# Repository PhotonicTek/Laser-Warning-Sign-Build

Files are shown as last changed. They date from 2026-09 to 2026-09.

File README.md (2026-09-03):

# Laser Warning Sign
---
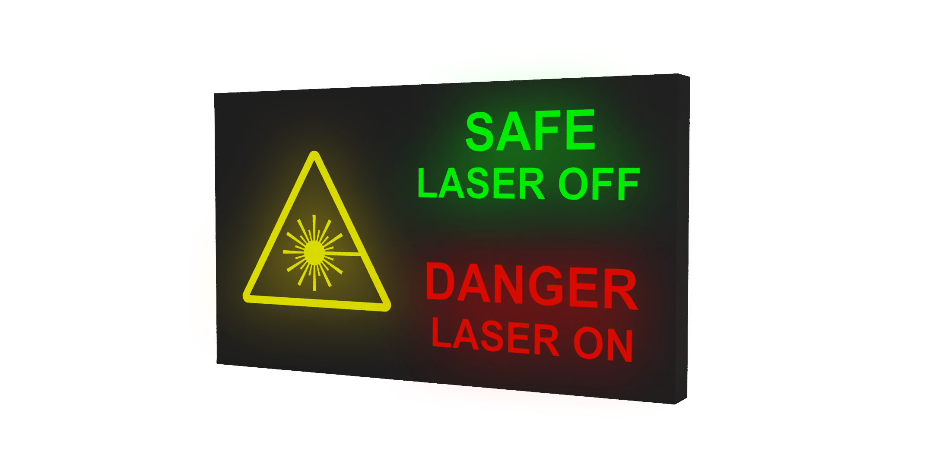
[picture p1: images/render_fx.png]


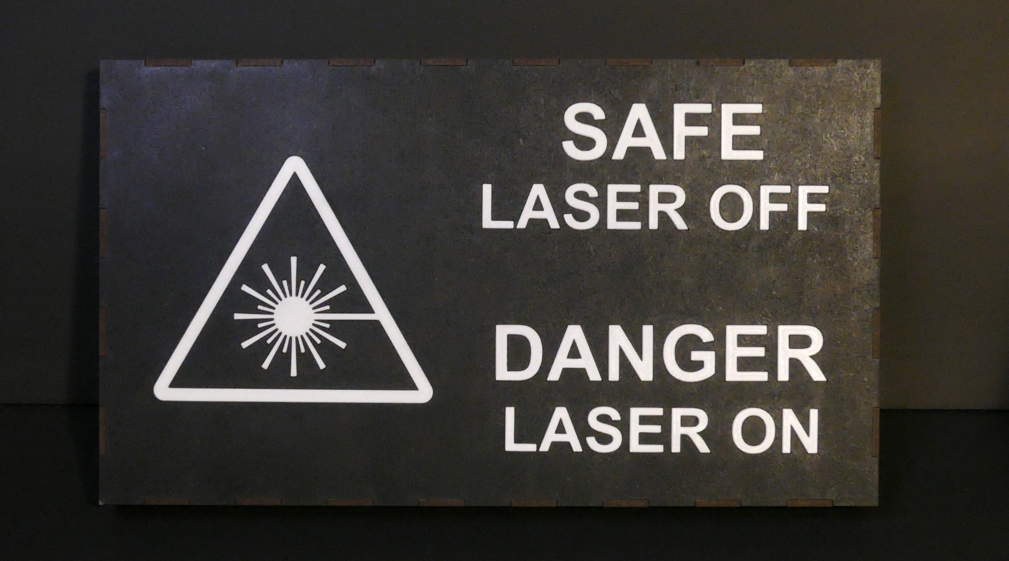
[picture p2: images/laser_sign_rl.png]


---

## Background

I wanted a warning sign that's better than just a paper sign taped to the door. This repo contains everything needed to reproduce the sign and its matching remote: schematics, code, 3D model files, laser cutter files, a parts list, and image assets.

Video walkthrough of the design and build process: *[[Building a Wireless Laser Warning Sign]](https://youtu.be/S0kvliff3TM)*

---

## Overview

The sign has two states, safe and danger, lit from behind by an LED strip through a diffuse layer, with laser-cut lettering and icon. It's fully battery-operated, wirelessly switched by a handheld remote, and mounts with command strips.

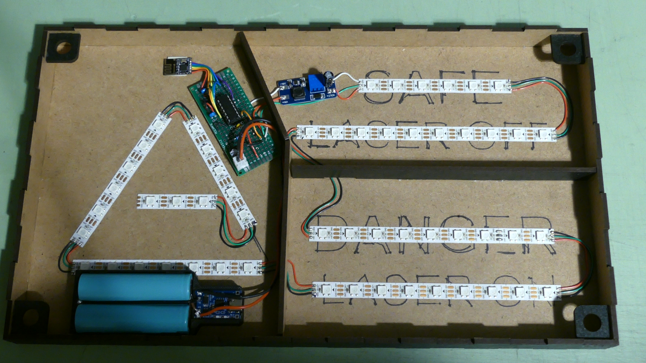
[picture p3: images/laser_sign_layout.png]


### Sign Electronics
- **ATtiny84** — main microcontroller, chosen for size, low-power sleep states, and flexible power input
- **nRF24** — wireless transceiver, receives state changes from the remote
- **AP7313** — low-dropout regulator, steps battery voltage down to keep the nRF24 under its 3.6V max
- **MT3608** — boost converter, steps battery voltage up to 5V for the LED strip
- **WS2812B (NeoPixel) LED strip** — backlighting for the lettering
- **TP4056** — battery management / charging
- **2x 18650 cells 3000mAh (parallel)** — ~6000mAh combined capacity; recycled cells were tested and verified to ~2780mAh
- **IRLML6402TRPBF** high-side MOSFET — cuts power to the boost converter and LEDs when the sign is off, to eliminate idle draw from that stage

### Remote Electronics
Same microcontroller and transceiver as the sign, with button inputs instead of an LED strip. Powers on when the power button is pressed and transmits the selected sign state.

### Power Notes
- Idle draw when duty-cycled (~1s sleep, brief wake to check for a signal, ~2.5% duty cycle): averages ~640µA, giving roughly a year of standby life
- With the sign on (LEDs lit): ~560mA, ~10 hours of runtime

The ATtiny84 doesn't have onboard USB, so it's flashed using an Arduino Uno as an ISP programmer.

---

## Repository Contents

- Schematics are provided as source .json files plus image exports for viewing without a schematic program.
- 3D model files for the full sign and remote plus individual 3D-printed parts, all printing was done in PLA on a Bambu Lab P1S.
- LightBurn laser files are set up for 3mm hardboard. Additional DXF and SVG cut paths are also available.
- The BOM lists parts as used; substitutions are noted where relevant (see below).

---

## Substitution Notes

- Generic resistors, capacitors, and other passives can be substituted freely at the correct value/tolerance.
- The ATtiny84 and nRF24 modules are both common and easily sourced new. The nRF24 module comes in many shapes and sizes; the mini version was used in this project as it was what I had on hand.
- 18650 cells used here were recycled/harvested, capacity and health will very if you're sourcing your own.

---

## Known Issues / Things to Watch For

- The boost converter causes a brief voltage drop on power-up that can brown out the microcontroller and cause the LED strip to briefly show garbage colors. A large capacitor on the boost converter output and a small capacitor across the MOSFET gate (to slow its turn-on) fixes this. Both fixes have been implemented and are shown on the schematics in this repo.
- Make sure to burn the bootloader on the ATtiny84 before programming, skipping this leaves the clock running at the wrong speed.
- Light leakage around the lettering in the dark may need internal dividers depending on your enclosure tolerances.

---

## Licence

Everything in this repository — schematics, code, models, cut files, BOM, and images, is free to use, modify, and build on, for any purpose.

**No support is provided.** This is a documentation dump, not a maintained project. I won't be providing build help, debugging, or answering setup questions, use it at your own discretion.

---

## AI Use Disclaimer

Portions of this documentation were drafted with the use of AI writing tools and reviewed for accuracy against the physical build. All technical content (circuit design, firmware, and component selection) came from the actual build process. If you spot an error, please open an issue.

---

## See Also

- Video walkthrough: *[[Building a Wireless Laser Warning Sign]](https://youtu.be/S0kvliff3TM)*
- KiCad / EasyEDA (schematic tools): https://www.kicad.org / https://easyeda.com
- Krita (used for the initial sign mockup): https://krita.org

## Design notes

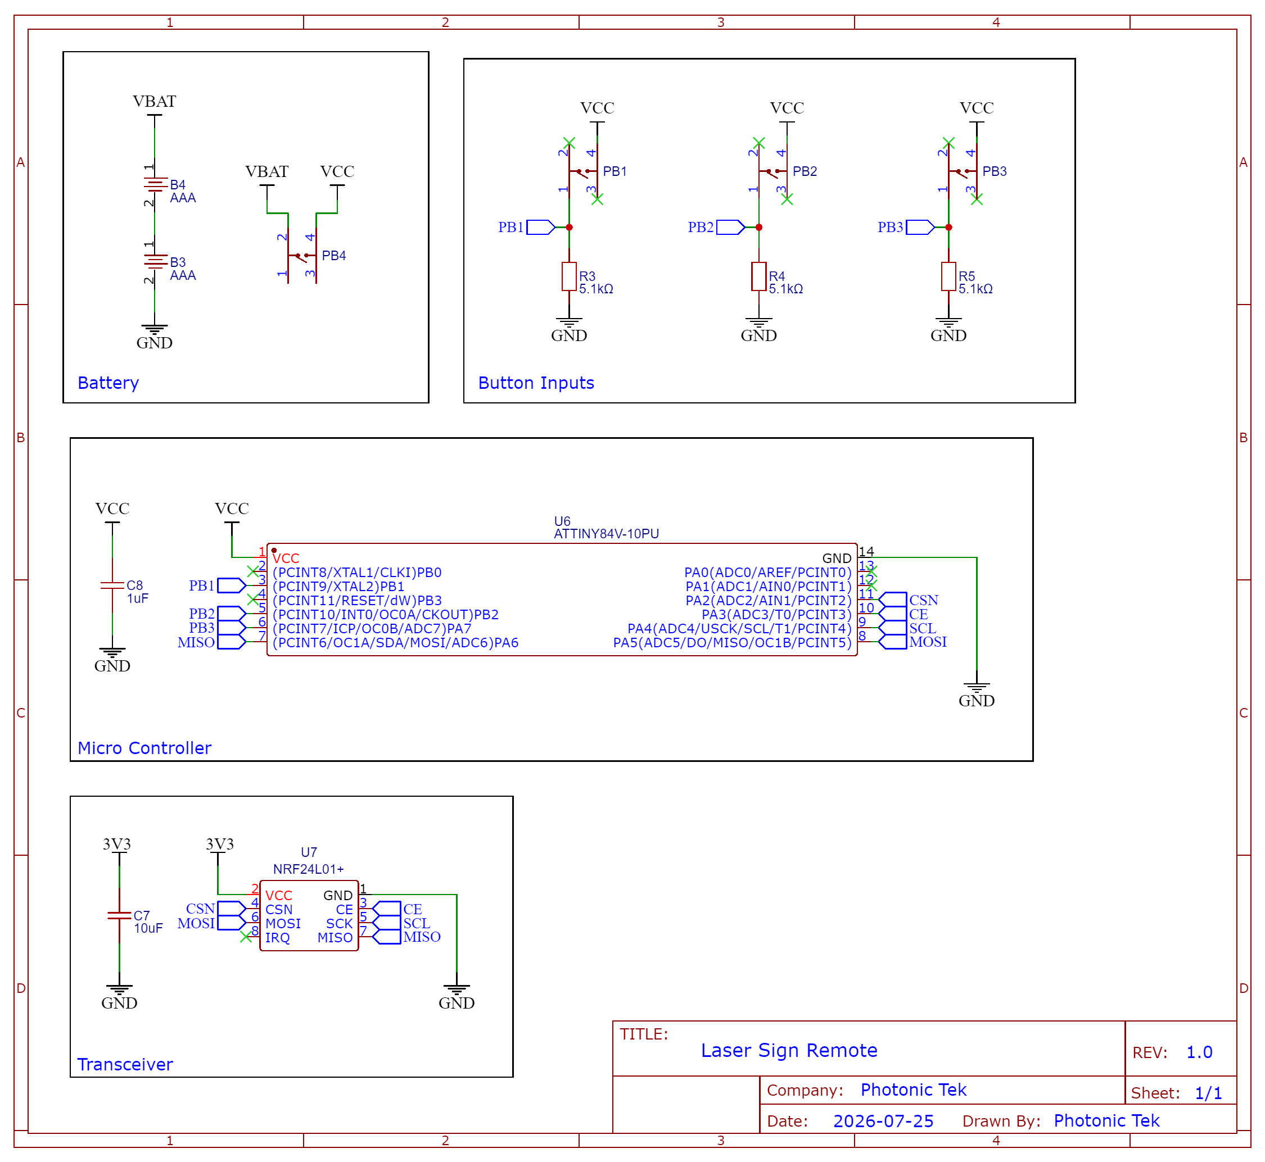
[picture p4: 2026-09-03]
schematics/Laser_Sign_Remote.png

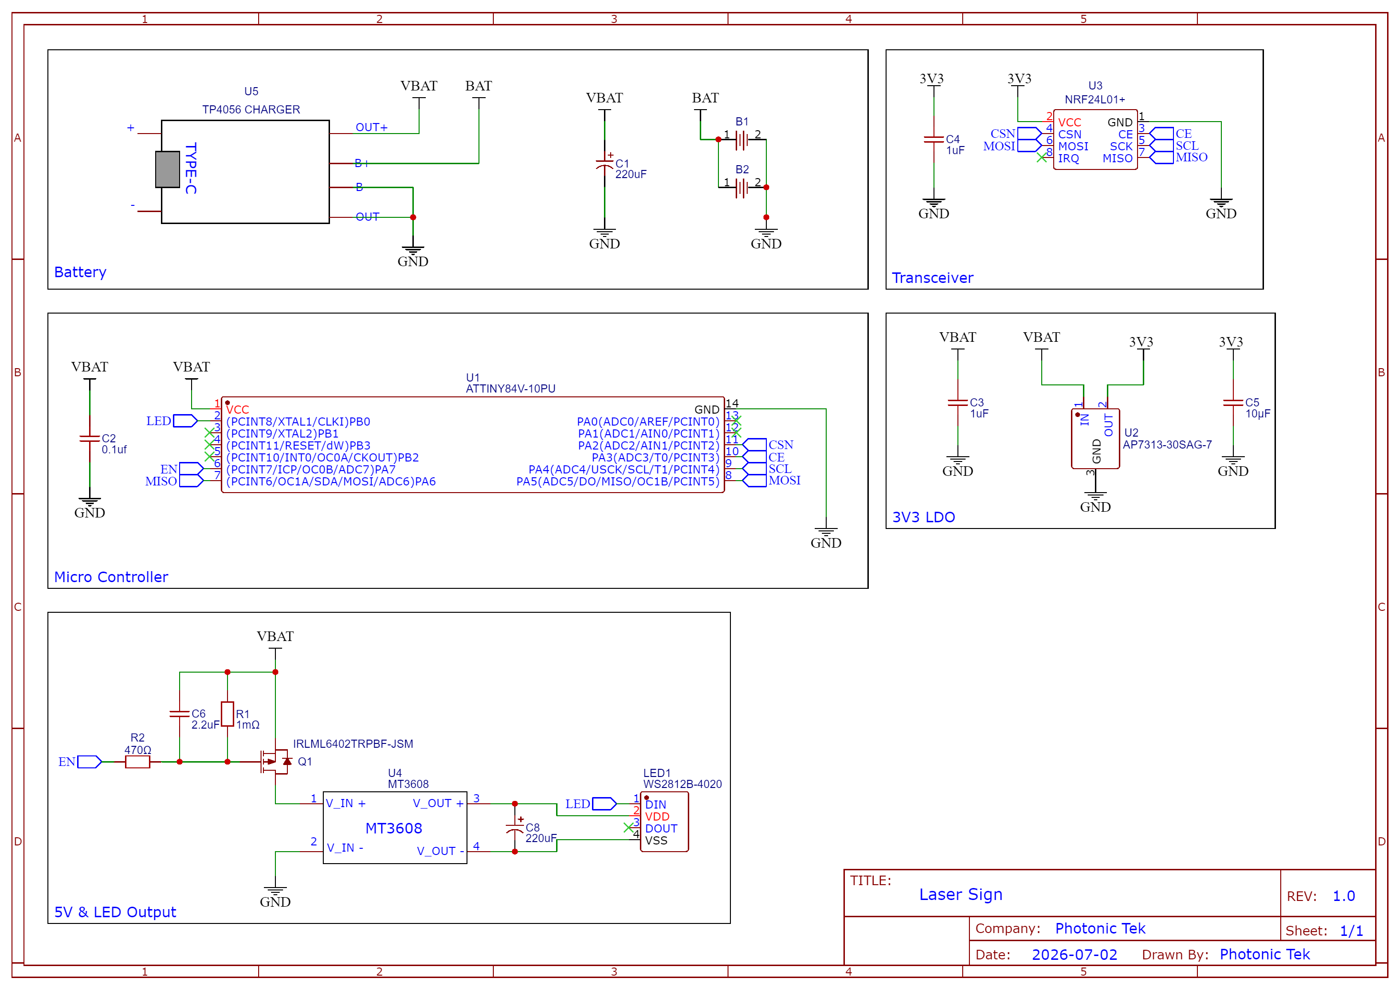
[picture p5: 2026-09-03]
schematics/Laser_Sign.png

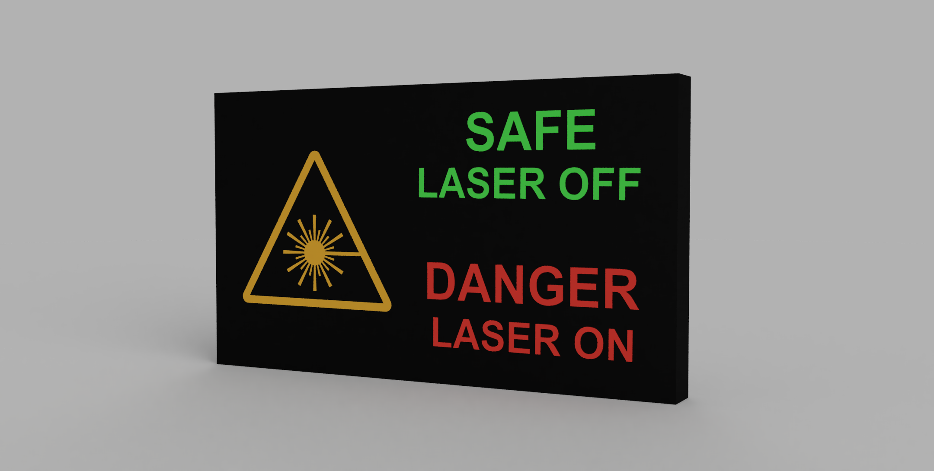
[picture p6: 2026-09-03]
images/render.png

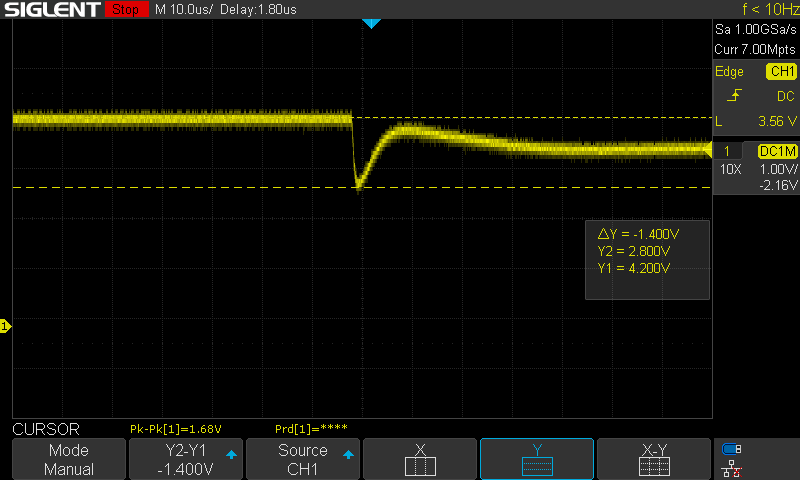
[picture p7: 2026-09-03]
images/Video_Asset2.png

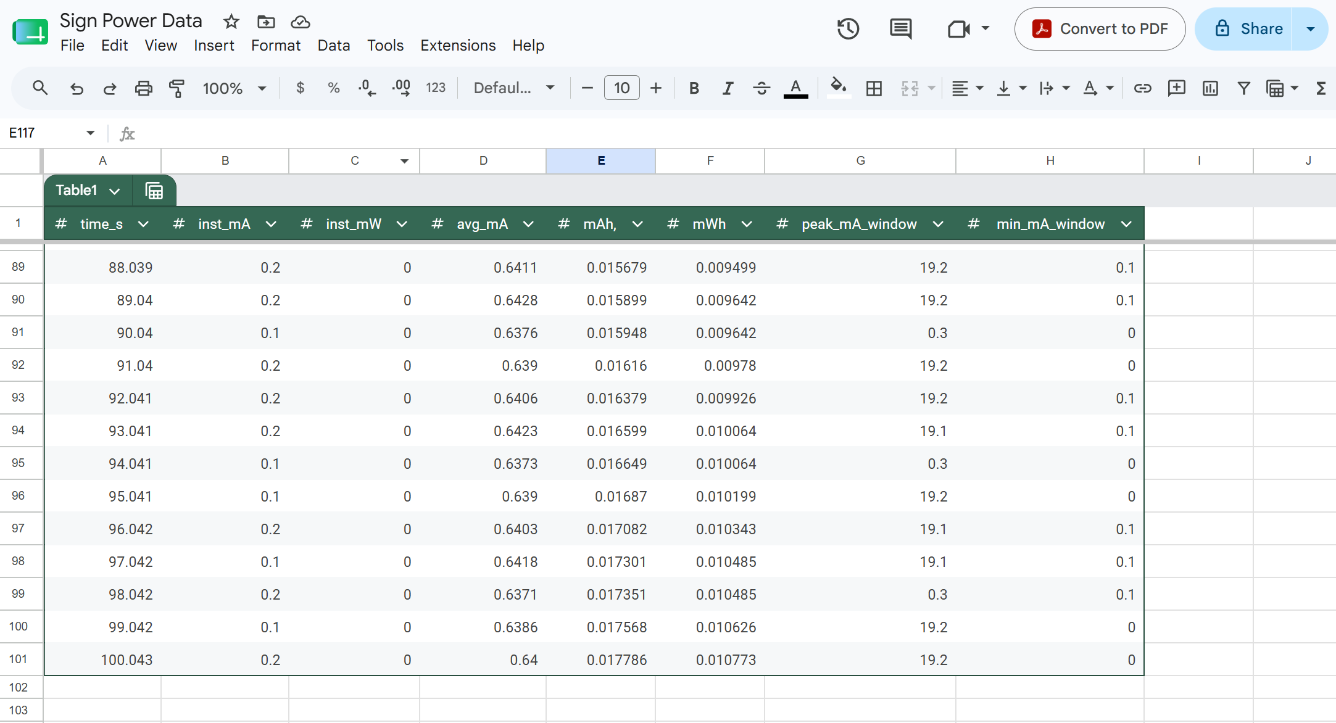
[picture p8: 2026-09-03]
images/Video_Asset5.png

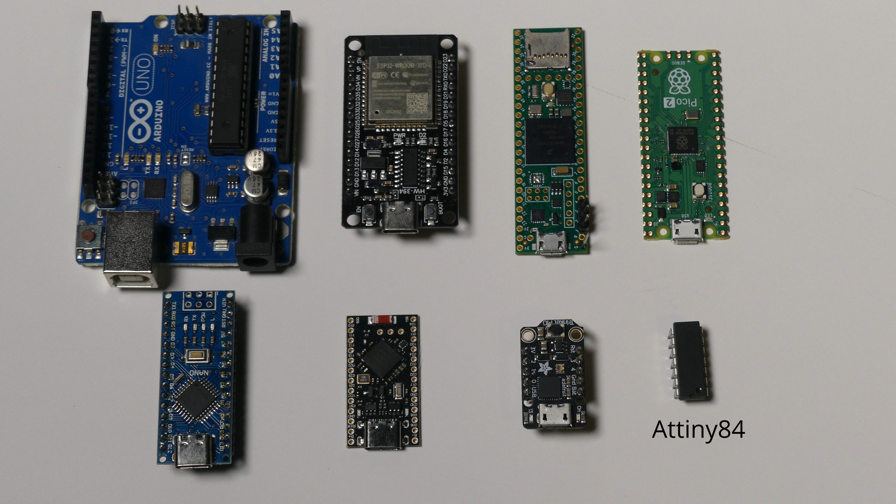
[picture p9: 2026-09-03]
images/Video_Asset1.jpg

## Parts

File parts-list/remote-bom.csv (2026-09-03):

ID | Designator | Quantity | Name | Notes / Link
1 | B3,B4 | 2 | AAA Battery
2 | C8 | 1 | 1uF
3 | C9 | 1 | 10uF
4 | R3,R4,R5 | 3 | 5.1kOhm
5 | PB1,PB2,PB3,PB4 | 4 | Tactile Button
6 | U6 | 1 | ATTINY84V-10PU | https://www.digikey.ca/en/products/detail/microchip-technology/ATTINY84V-10PU/1245918
7 | U7 | 1 | NRF24L01+ | https://www.aliexpress.com/item/1005009894884618.html

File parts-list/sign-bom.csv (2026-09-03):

ID | Designator | Quantity | Name | Notes / Link
1 | B1,B2 | 2 | 18650 Battery
2 | C1,C7 | 1 | 220uF
3 | C2 | 1 | 0.1uF
4 | C3,C4 | 2 | 1uF
5 | C5 | 1 | 10uF
6 | C6 | 1 | 2.2uF
7 | R1 | 1 | 1MOhm
8 | R2 | 1 | 470Ohm
9 | LED1 | 22" | WS2812B
10 | Q1 | 1 | IRLML6402TRPBF-JSM | https://www.digikey.ca/en/products/detail/infineon-technologies/IRLML6402TRPBF/811437
11 | U1 | 1 | ATTINY84V-10PU | https://www.digikey.ca/en/products/detail/microchip-technology/ATTINY84V-10PU/1245918
12 | U2 | 1 | AP7313-30SAG-7 | https://www.digikey.ca/en/products/detail/diodes-incorporated/AP7313-30SAG-7/4249716
13 | U3 | 1 | NRF24L01+ | https://www.aliexpress.com/item/1005009894884618.html
14 | U4 | 1 | MT3608 | https://www.aliexpress.com/item/1005009065980527.html
15 | U5 | 1 | TP4056-CHARGING-MODULE | https://www.aliexpress.com/item/1005012397354631.html

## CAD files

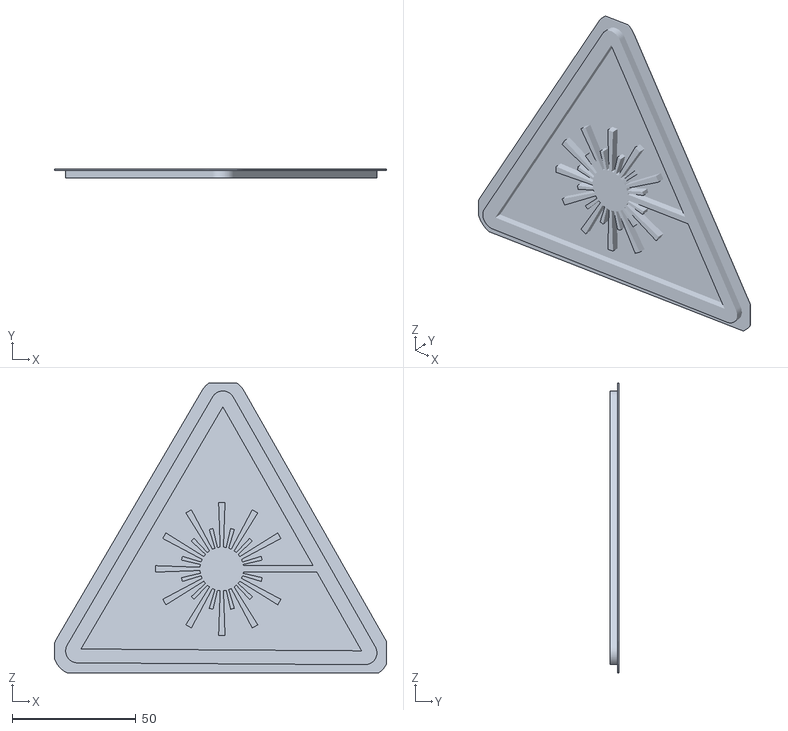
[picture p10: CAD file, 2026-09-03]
models/3d-printed-files/Laser Icon.stl
134.0 x 3.60 x 117.0

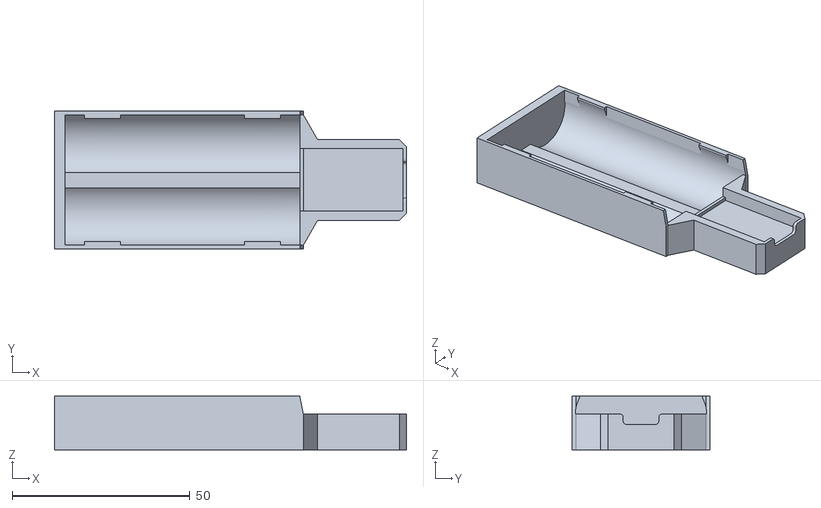
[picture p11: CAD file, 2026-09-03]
models/3d-printed-files/Battery holder.stl
99.0 x 38.7 x 15.1

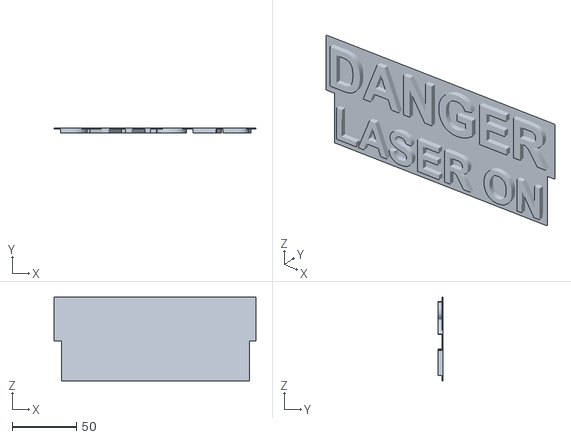
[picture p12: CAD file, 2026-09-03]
models/3d-printed-files/Test DANGER_LASER_ON.stl
157.0 x 3.60 x 65.0

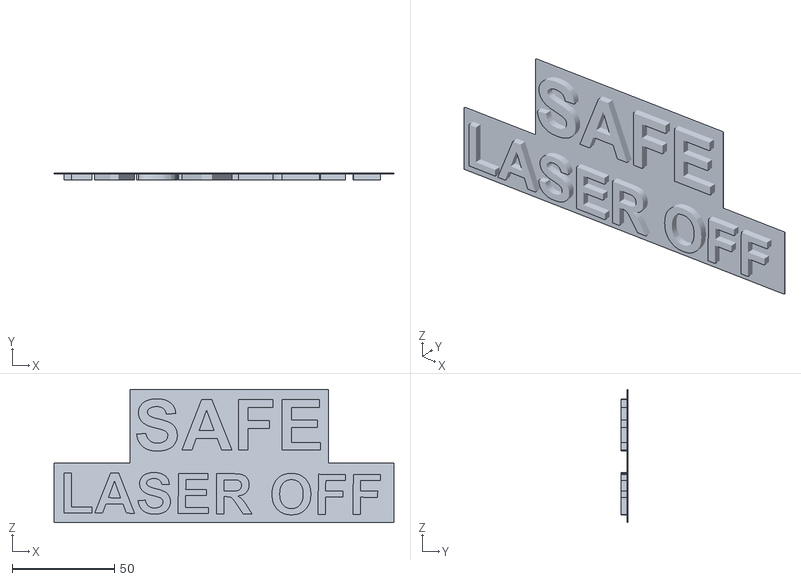
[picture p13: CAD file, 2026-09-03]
models/3d-printed-files/Text SAFE_LASER_OFF.stl
166.0 x 3.60 x 65.0

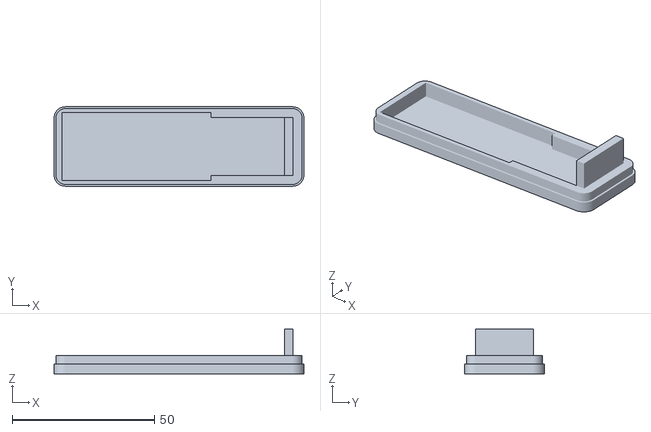
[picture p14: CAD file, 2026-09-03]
models/3d-printed-files/Remote bottom.stl
88.0 x 28.0 x 15.7

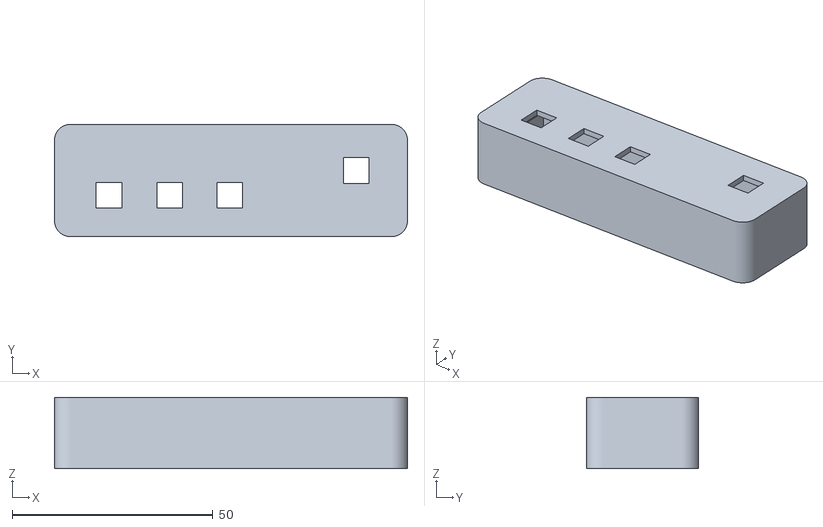
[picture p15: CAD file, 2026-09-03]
models/3d-printed-files/Remote top.stl
88.0 x 28.0 x 17.8

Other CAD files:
laser-files/Laser cutpaths.dxf

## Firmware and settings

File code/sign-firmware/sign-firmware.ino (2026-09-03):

#include <SPI.h>
#include <RF24.h>
#include <FastLED.h>
#include <avr/sleep.h>
#include <avr/wdt.h>
#include <avr/power.h>
#include <avr/interrupt.h>

// ---------- Pin definitions ----------
#define CE_PIN        3   // PA3
#define CSN_PIN       2   // PA2
#define LED_DATA_PIN  10  // PB2
#define BOOST_EN_PIN  7   // PA7

// ---------- LED layout ----------
#define ZONE0_LEN       16
#define ZONE1_LEN       18
#define ZONE2_LEN       21

#define NUM_ZONES       3
#define NUM_LEDS        (ZONE0_LEN + ZONE1_LEN + ZONE2_LEN)  // 55
#define MAX_BRIGHTNESS  100   // hard cap, out of 255

CRGB leds[NUM_LEDS];

const uint16_t zoneLen[NUM_ZONES]   = { ZONE0_LEN, ZONE1_LEN, ZONE2_LEN };
const uint16_t zoneStart[NUM_ZONES] = {
  0,
  ZONE0_LEN,
  ZONE0_LEN + ZONE1_LEN
};

// ---------- Radio ----------
RF24 radio(CE_PIN, CSN_PIN);
const byte address[6] = "43561";

// ---------- Sleep / listen tuning ----------
#define RADIO_POWERUP_SETTLE_MS   5     // time for nRF24 to leave power-down
#define RADIO_LISTEN_WINDOW_MS    20   // how long to listen per wake

// ---------- State ----------
bool ledsEnabled = false;


ISR(WDT_vect) {
}

void setupWatchdogForSleep() {
  cli();
  wdt_reset();
  MCUSR &= ~(1 << WDRF);              // clear watchdog reset flag
  WDTCSR |= (1 << WDCE) | (1 << WDE); // enable config change window
  WDTCSR = (1 << WDIE) | (1 << WDP2) | (1 << WDP1);
  sei();
}

// ---------- Power control (LED boost converter) ----------
void boostEnable() {
  digitalWrite(BOOST_EN_PIN, LOW);   // LOW = MOSFET ON = boost enabled
}

void boostDisable() {
  digitalWrite(BOOST_EN_PIN, HIGH);  // HIGH = MOSFET OFF = boost disabled
}

// Turn power on only if it isn't already on, with a short settle
// delay so the boost converter's output is stable before we clock
// out LED data.
void powerOnIfNeeded() {
  if (!ledsEnabled) {
    boostEnable();
    delay(100);
    ledsEnabled = true;
  }
}

void powerOff() {
  fill_solid(leds, NUM_LEDS, CRGB::Black);
  FastLED.show();

  pinMode(LED_DATA_PIN, OUTPUT);
  digitalWrite(LED_DATA_PIN, LOW);

  boostDisable();
  ledsEnabled = false;
}

// ---------- Zone helpers ----------
// zoneIndex is 0/1/2 (zone1/zone2/zone3 in the command comments
// above). Uses the zoneStart/zoneLen tables so each zone can have a
// different pixel count.
void setZone(uint8_t zoneIndex, CRGB color) {
  uint16_t start = zoneStart[zoneIndex];
  uint16_t count = zoneLen[zoneIndex];
  for (uint16_t i = start; i < start + count; i++) {
    leds[i] = color;
  }
}

// ---------- Command handling ----------
void handleCommand(char cmd) {
  switch (cmd) {
    case '1':  // ON
      powerOnIfNeeded();
      setZone(0, CRGB::Green);
      setZone(1, CRGB::Black);
      setZone(2, CRGB::Yellow);
      FastLED.show();
      break;

    case '2':  // ENABLE
      powerOnIfNeeded();
      setZone(0, CRGB::Black);
      setZone(1, CRGB::Red);
      setZone(2, CRGB::Yellow);
      FastLED.show();
      break;

    case '0':  // OFF
      powerOff();
      break;

    default:
      // Unknown command byte - ignore.
      break;
  }
}

// ---------- Sleep cycle ----------
// Called from loop() whenever the sign is off. Puts the MCU into
// power-down sleep for ~1s, wakes, briefly powers up the radio and
// listens for a command, then either handles it or goes back to
// sleep. Returns once either a command has been handled or the
// listen window has expired with nothing received.
void enterSleepCycle() {
  // Drop the radio into its own low-power state before sleeping.
  radio.powerDown();

  setupWatchdogForSleep();

  set_sleep_mode(SLEEP_MODE_PWR_DOWN);
  sleep_enable();
#if defined(BODS) && defined(BODSE)
  sleep_bod_disable();  // best-effort brown-out-detector disable during sleep
#endif
  sleep_cpu();           // <-- MCU halts here until the WDT ISR fires
  sleep_disable();5

  // Woken up - bring the radio back and listen briefly.
  radio.powerUp();
  delay(RADIO_POWERUP_SETTLE_MS);
  radio.startListening();

  uint32_t listenStart = millis();
  while (millis() - listenStart < RADIO_LISTEN_WINDOW_MS) {
    if (radio.available()) {
      char cmd = 0;
      radio.read(&cmd, sizeof(cmd));
      handleCommand(cmd);

      if (ledsEnabled) {
        // Sign just got turned on - bail out of the sleep cycle and
        // let loop() take over with continuous polling. Radio is
        // already powered up and listening, nothing more to do.
        return;
      }
      // Command was OFF (or unknown) while already off - keep
      // listening out the rest of this window in case more packets
      // are queued, then fall through to going back to sleep.
    }
  }
  // Nothing (further) received this cycle - go back to sleep next
  // time loop() calls us.
}

// ---------- Setup ----------
void setup() {
  pinMode(BOOST_EN_PIN, OUTPUT);
  boostDisable();  // start with LEDs unpowered

  pinMode(LED_DATA_PIN, OUTPUT);
  digitalWrite(LED_DATA_PIN, LOW);

  FastLED.addLeds<WS2812, LED_DATA_PIN, GRB>(leds, NUM_LEDS);
  FastLED.setBrightness(MAX_BRIGHTNESS);
  fill_solid(leds, NUM_LEDS, CRGB::Black);
  FastLED.show();

  // We don't use the ADC at all - make sure it's off.
  power_adc_disable();

  // Radio init - retry a few times in case of a slow-starting
  // regulator/brownout on power-up.
  bool radioOk = false;
  for (uint8_t attempt = 0; attempt < 5 && !radioOk; attempt++) {
    radioOk = radio.begin();
    if (!radioOk) delay(50);
  }

  radio.openReadingPipe(0, address);
  radio.setPALevel(RF24_PA_LOW);
  radio.setDataRate(RF24_1MBPS);
  radio.setCRCLength(RF24_CRC_16);
  radio.setRetries(5, 15);
  radio.setAutoAck(true);
  radio.startListening();

  if (!radioOk) {
    for (uint8_t i = 0; i < 3; i++) {
      setZone(0, CRGB::Red);
      FastLED.show();
      delay(150);
      setZone(0, CRGB::Black);
      FastLED.show();
      delay(150);
    }
  }

  // Start life in the low-power sleep/poll cycle (ledsEnabled is
  // already false at this point).
}

// ---------- Main loop ----------
void loop() {
  if (ledsEnabled) {
    // Fully awake mode
    while (radio.available()) {
      char cmd = 0;
      radio.read(&cmd, sizeof(cmd));
      handleCommand(cmd);
    }
  } else {
    enterSleepCycle();
  }
}

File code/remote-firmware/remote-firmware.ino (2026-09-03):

// ---- Debug serial (optional, off by default) ----------------------
// ATtiny84 has no hardware UART. Flip this to 1 for bench testing with
// SoftwareSerial on the two spare pins (PB0 = TX, PA0 = RX, unused).
// Leave it 0 for the final build in the remote -- saves flash and
// avoids the extra pins being tied up.
#define DEBUG_SERIAL 0

#if DEBUG_SERIAL
  #include <SoftwareSerial.h>
  #define DBG_RX PIN_PA0
  #define DBG_TX PIN_PB0
  SoftwareSerial dbg(DBG_RX, DBG_TX);
  #define DBG_BEGIN(baud)   dbg.begin(baud)
  #define DBG_PRINT(...)    dbg.print(__VA_ARGS__)
  #define DBG_PRINTLN(...)  dbg.println(__VA_ARGS__)
#else
  #define DBG_BEGIN(baud)
  #define DBG_PRINT(...)
  #define DBG_PRINTLN(...)
#endif

// RF24 auto-detects ATtiny84 (defines RF24_TINY internally) and drives
// the USI peripheral directly -- no <SPI.h> include needed here.
#include <RF24.h>

#define CE_PIN  PIN_PA3
#define CSN_PIN PIN_PA2
RF24 radio(CE_PIN, CSN_PIN);
const byte address[6] = "43561";

#define BTN_ON     PIN_PB1
#define BTN_OFF    PIN_PA7
#define BTN_ENABLE PIN_PB2

#define BURST_DURATION_MS  1500   // total time to repeat the command
#define BURST_INTERVAL_MS  15     // gap between repeats within a burst
#define DEBOUNCE_MS        50

void sendBurst(char c, const char* label) {
  DBG_PRINT("Sending '");
  DBG_PRINT(label);
  DBG_PRINTLN("' burst...");

  radio.stopListening();

  uint32_t start = millis();
  uint16_t sent = 0;
  uint16_t acked = 0;

  while (millis() - start < BURST_DURATION_MS) {
    bool ok = radio.write(&c, sizeof(c));
    sent++;
    if (ok) acked++;
    delay(BURST_INTERVAL_MS);
  }

  DBG_PRINT(label);
  DBG_PRINT(": sent ");
  DBG_PRINT(sent);
  DBG_PRINT(", acked ");
  DBG_PRINTLN(acked);
}

// Waits for the currently-pressed button to be released so a single
// press doesn't get interpreted as being held for the whole burst.
void waitForRelease(uint8_t pin) {
  while (digitalRead(pin) == HIGH) {
    delay(10);
  }
  delay(DEBOUNCE_MS);
}

void setup() {
  DBG_BEGIN(9600);
  delay(500);
  DBG_PRINTLN("=== TX starting ===");

  // External pull-down resistors are used on these buttons, so no
  // internal pull-up. Pins idle LOW and the button pulls them HIGH
  // when pressed.
  pinMode(BTN_ON, INPUT);
  pinMode(BTN_OFF, INPUT);
  pinMode(BTN_ENABLE, INPUT);

  if (!radio.begin()) {
    DBG_PRINTLN("ERROR: nRF24 not responding! Check wiring.");
    while (1) {} // halt
  }

  radio.openWritingPipe(address);
  radio.setPALevel(RF24_PA_LOW);
  radio.setDataRate(RF24_1MBPS);
  radio.setCRCLength(RF24_CRC_16);
  radio.setRetries(5, 15);
  radio.setAutoAck(true);
  radio.stopListening();

  DBG_PRINTLN("Radio initialized. Waiting for button presses...");
}

void loop() {
  if (digitalRead(BTN_ON) == HIGH) {
    DBG_PRINTLN("Button: ON pressed");
    sendBurst('1', "ON");
    waitForRelease(BTN_ON);
  }

  if (digitalRead(BTN_OFF) == HIGH) {
    DBG_PRINTLN("Button: OFF pressed");
    sendBurst('0', "OFF");
    waitForRelease(BTN_OFF);
  }

  if (digitalRead(BTN_ENABLE) == HIGH) {
    DBG_PRINTLN("Button: ENABLE pressed");
    sendBurst('2', "ENABLE");
    waitForRelease(BTN_ENABLE);
  }
}
